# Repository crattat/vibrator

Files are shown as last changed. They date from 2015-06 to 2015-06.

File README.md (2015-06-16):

# vibrator
The vibrator is a device for vibration analysis for brushless motors and propellers. Currently it uses a MPU6050 chip for vibration analysis and an OPB732 photoelectric sensor to measure the revolution. All together is controlled with an Arduino Due and a touch display with a SD card interface. The results are evaluated with statistical analysis with R.

## Hardware
I'm using an Arduino Due together with an SD shield and 2.8" touch display. To wire the sensors and ESC a protoshield is put between SD shield and Arduino. In the cases folder you will find 3D designs and ready to print STL files for cases for the Arduino and also for the sensors to mount it properly. 

## Functions
Currently these functions are available:

* Measure and log revolution into a logfile to SD card
* Control a brushless motor via servo lib to run at predefined revolutions
* Automatically do a full vibration analysis at different revolutions
* Just watch all the sensor data graphically in a plot and as text
* Manage the files on SD card

## Restrictions
The MPU6050 is controlled through the I2C bus. This is quite limiting as it delivers not enough data per second. Just a few hundred samples is not enough to measure vibration frequency higher than a few hundred Hz. The results are good to compare motors or propellers reasonably anyway. For proper analysis of the concrete frequency with the strongest vibrations different sensors are required. I'm currently looking for better qualified or additional sensors.  

## Planned Enhancements
Extensions for the vibrator will be:

* A shunt to measure in addition the power consumption during the other tests
* A weighing cell to measure thrust during the tests. 

## Notes
To get the 2.8" SainSmart touch giving the correct coordinates the following defines have been adjusted in IDB02_touch.cpp:

```c++
#define PixSizeX	13.78

#define PixOffsX	411

#define PixSizeY	11.01

#define PixOffsY	378

```

The DueTimer lib conflicts with the Servo lib and the following define in the DueTimer.h file has been defined:

```c++
#define USING_SERVO_LIB	true
``` 
This makes several timers unavailabe.

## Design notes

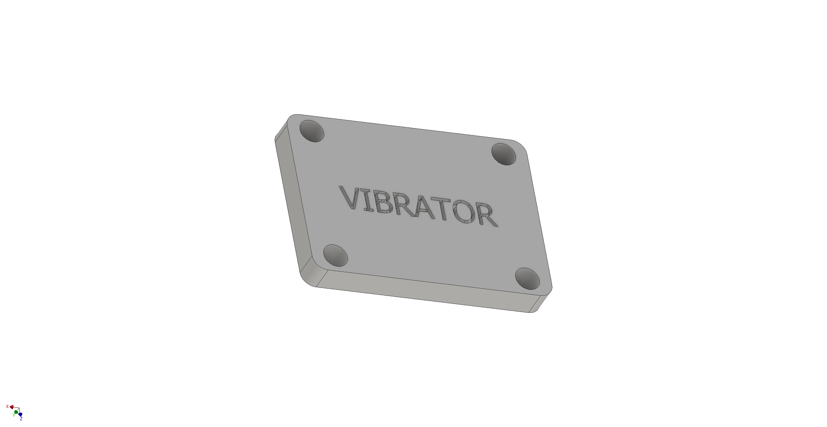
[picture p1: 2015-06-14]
Cases/MPU6050_CASE_TOP.jpg

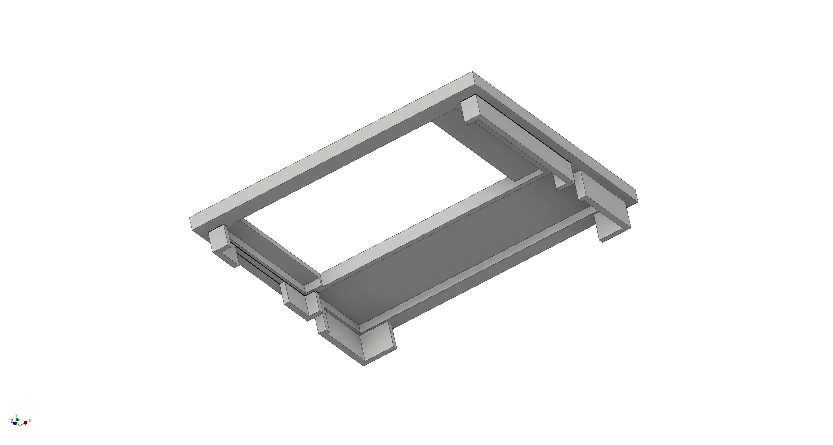
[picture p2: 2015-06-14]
Cases/ARDUINO_DUE_CASE_TOP.jpg

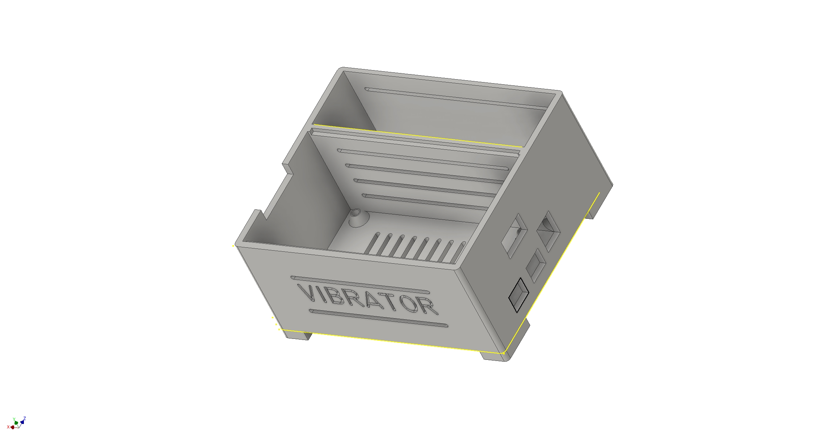
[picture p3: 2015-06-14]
Cases/ARDUINO_DUE_CASE_BOTTOM.jpg

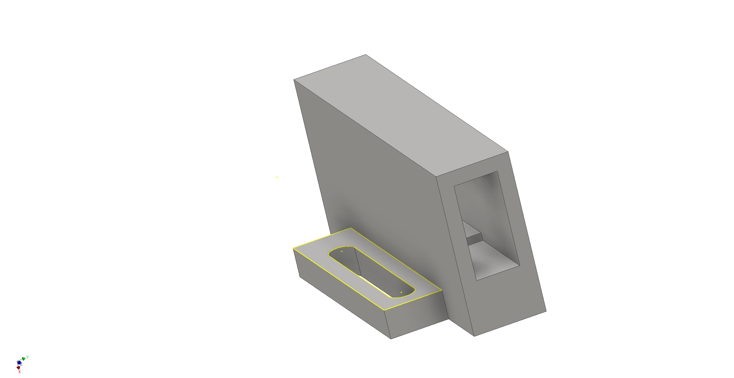
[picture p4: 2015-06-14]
Cases/OPB732_CASE_BOTTOM.jpg

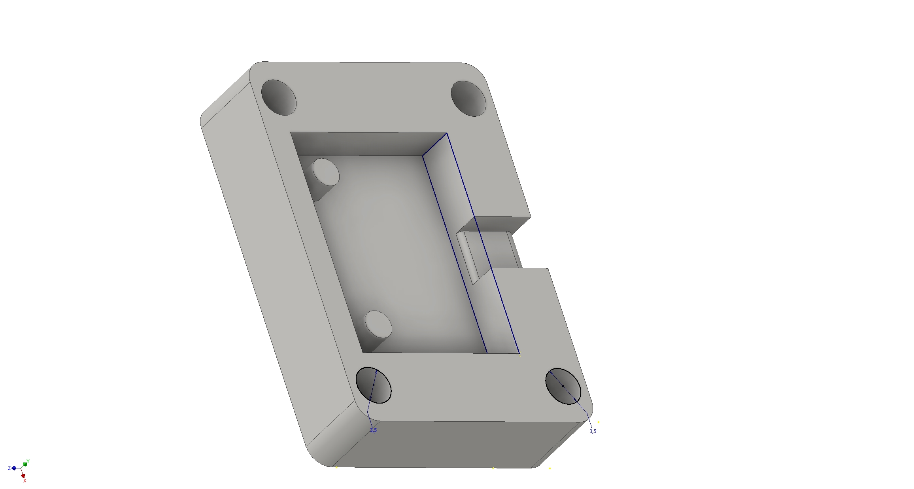
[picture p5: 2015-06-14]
Cases/MPU6050_CASE_BOTTOM.jpg

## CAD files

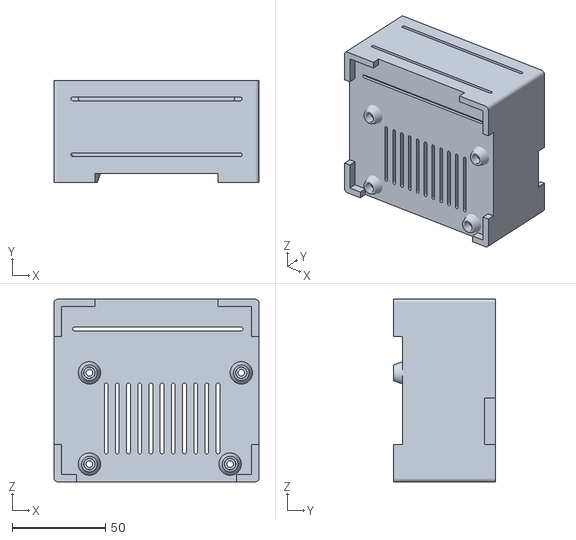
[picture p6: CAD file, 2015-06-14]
Cases/ARDUINO_DUE_CASE_BOTTOM.stl
110.0 x 55.0 x 98.0

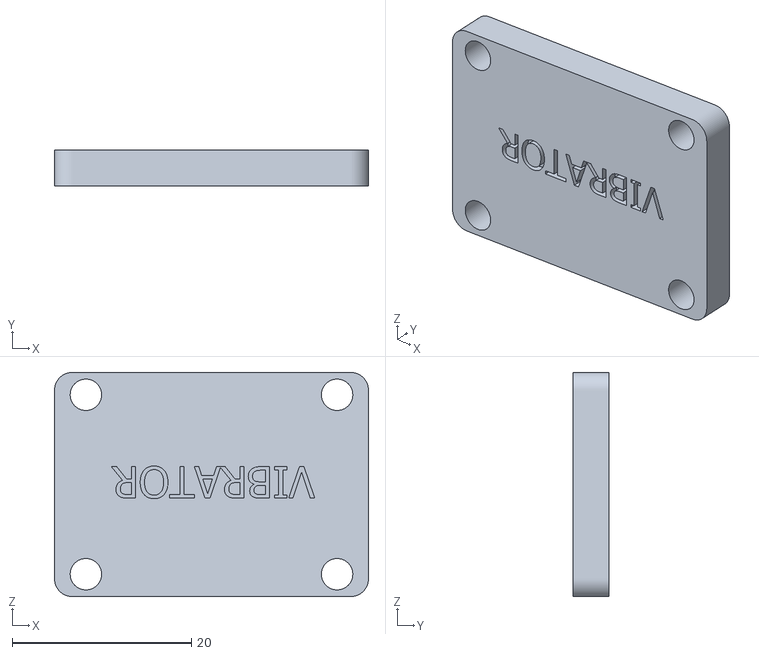
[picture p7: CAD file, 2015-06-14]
Cases/MPU6050_CASE_TOP.stl
35.0 x 4.00 x 25.0

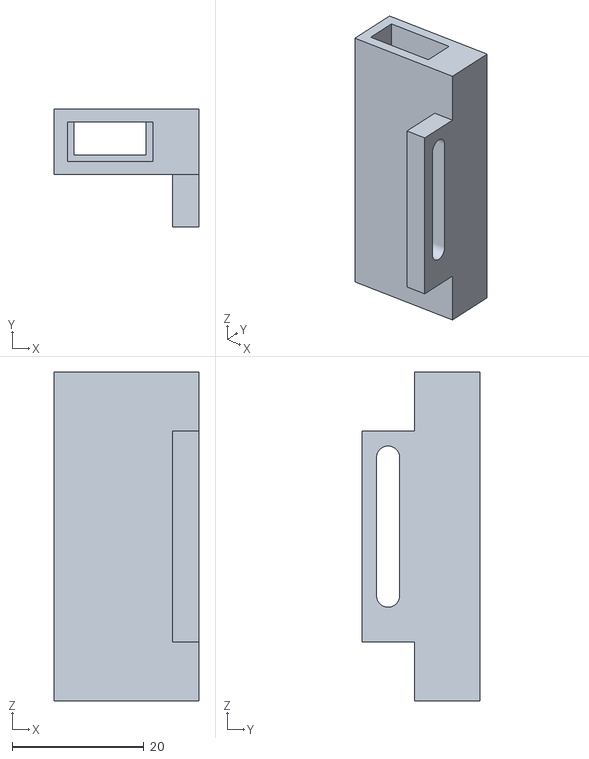
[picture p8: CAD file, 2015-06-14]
Cases/OPB732_CASE_BOTTOM.stl
22.0 x 18.0 x 50.0

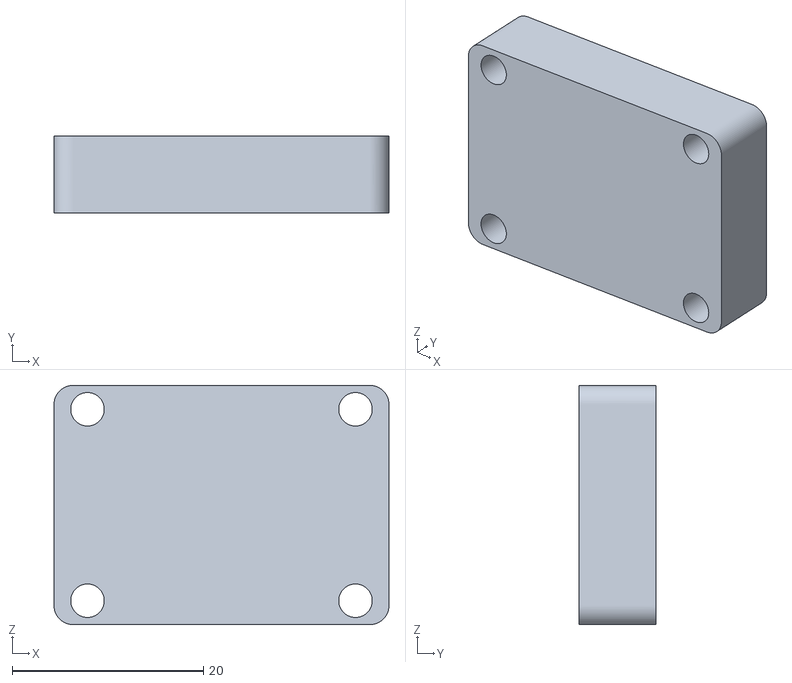
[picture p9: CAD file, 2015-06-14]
Cases/MPU6050_CASE_BOTTOM.stl
35.0 x 8.00 x 25.0

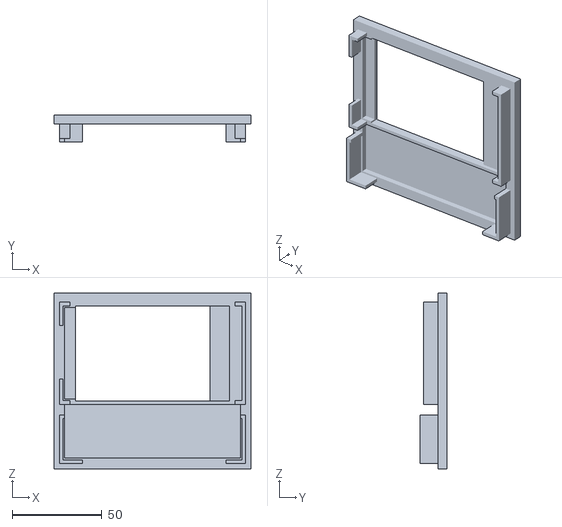
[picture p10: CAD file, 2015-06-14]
Cases/ARDUINO_DUE_CASE_TOP.stl
110.0 x 15.0 x 98.0

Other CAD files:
Cases/ARDUINO_DUE_CASE_BOTTOM.ipt
Cases/ARDUINO_DUE_CASE_TOP.ipt
Cases/MPU6050_CASE_BOTTOM.ipt
Cases/MPU6050_CASE_TOP.ipt
Cases/OPB732_CASE_BOTTOM.ipt

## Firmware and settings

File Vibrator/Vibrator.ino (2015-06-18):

// =========================================================================
// included libraries
// =========================================================================
#include "SPI.h"
#include <SdFat.h>
#include <UTFT.h>
#include <ITDB02_Touch.h>
#include <Servo.h>
#include <I2Cdev.h>
#include <MPU6050.h>

// =========================================================================
// Arduino Wire library is required if I2Cdev I2CDEV_ARDUINO_WIRE
// implementation is used in I2Cdev.h
// =========================================================================
#if I2CDEV_IMPLEMENTATION == I2CDEV_ARDUINO_WIRE
#include <Wire.h>
#endif

#include <DueTimer.h>

// =========================================================================
// includes from sketch
// =========================================================================
#include "Defines.h"
#include "IMUData.h"
#include "Logger.h"
#include "Menu.h"
#include "Screen.h"
#include "Views.h"

// =========================================================================
// devices
// =========================================================================
Logger            _logger;
Screen            _screen;
MPU6050           _mpu6050;

// =========================================================================
// navigation and display stuff
// =========================================================================
bool              _navigationNeedsUpdate = false;
Menu*             _activeMenu = 0;
int16_t           _activeAction = 0;
uint32_t          _last100msUpdate = 0;
uint32_t          _last25msUpdate = 0;
uint32_t          _last10msUpdate = 0;

Menu              _mainMenu(&_screen, "Vibrator V1");
Menu              _sensorCheckMenu(&_screen, "Sensor Check");
Menu              _revMeterMenu(&_screen, "Rev Meter");
Menu              _revControlMenu(&_screen, "Rev Control");
Menu              _vibMeterMenu(&_screen, "Vibration Meter");
Menu              _settingsMenu(&_screen, "Settings");

Views             _views(&_screen);

// =========================================================================
// revolution measuring
// =========================================================================
volatile bool     _revlow = false;
volatile int32_t  _revpeaks = 0;
volatile int32_t  _revcount = 0;
volatile int32_t  _currentRevolution = 0;
volatile int32_t  _revolution = 0;

// =========================================================================
// IMU measure data
// =========================================================================
IMUData           _imuData;

// =========================================================================
// control motor
// =========================================================================
Servo  _esc;
volatile int      _escTargetRev = 0;
volatile int      _escCurrentLevel = 0;
volatile int      _escLastLevel = 0;

// =========================================================================
// states for automatic measuring
// =========================================================================
uint32_t         _testStart;
uint8_t          _step;

volatile  int32_t _revvalue = 0;

// =========================================================================
// 60 kHz timer to measure the revolution. To be accurate enough it is
// required to get updates every 60deg of rotation, i.e. the measuring
// unit that is used must indicate 6 times per rotation a change. In
// the original project this is done by glueing 6 markes of 3deg width
// on the engine cone.
// =========================================================================
void measureRevolutionTimer()
{
  // measure revolution
  // wait until channel 0 completed conversion
  while ((ADC->ADC_ISR & 0x80) == 0);
  // read channel 0
  _revvalue = ADC->ADC_CDR[7];
  // this is the normal analogRead which takes 40us by default, which is too slow for 60 kHz
  // int32_t _revvalue = analogRead(REV_METER_PIN);
  _revcount++;

  // here we measure low-high slopes
  if (_revvalue < 1000)
  {
    // if already low don't measure
    if (!_revlow)
    {
      _revpeaks++;
    }
    _revlow = true;
  }
  else
  {
    _revlow = false;
  }

  _currentRevolution = TIMER_REVOLUTION_FREQUENCY * _revpeaks / _revcount;

  if (_revcount > TIMER_REVOLUTION_FREQUENCY / 6)
  {
    _revolution = _currentRevolution;
    _revcount = 0;
    _revpeaks = 0;
  }
}


// =========================================================================
// 50 Hz timer to update the servo when any related mode is active.
// The current revolution is compared to the wanted target revolution.
// If current revolution is lower or higher the output PWM is increased
// or decreased correspondingly.
// =========================================================================
void controlServoTimer()
{
  switch (_activeAction)
  {
    case ACTION_ESC_CONTROL_1000U:
    case ACTION_ESC_CONTROL_2000U:
    case ACTION_ESC_CONTROL_3000U:
    case ACTION_ESC_CONTROL_4000U:
    case ACTION_ESC_CONTROL_5000U:
    case ACTION_VIB_METER_RECORD:

      uint16_t revMin = _revolution * 10;

      if (abs(revMin - _escTargetRev) < 100)
      {
        return;
      }

      if (revMin < _escTargetRev)
      {
        _escCurrentLevel++;
      }
      if (revMin > _escTargetRev)
      {
        _escCurrentLevel--;
      }

      if (_escCurrentLevel > REV_ESC_RANGE)
      {
        _escCurrentLevel = REV_ESC_RANGE;
      }
      else if (_escCurrentLevel < 0)
      {
        _escCurrentLevel = 0;
      }

      // don't set the same timing again
      if (_escLastLevel != _escCurrentLevel)
      {
        _escLastLevel = _escCurrentLevel;
        _esc.writeMicroseconds(map(_escCurrentLevel, 0, REV_ESC_RANGE, 800, 2000));
      }
      break;
  }
}

// =========================================================================
// Collect all sensor data in the imu data.
// =========================================================================
void updateSensorSamples()
{
  // collect from MPU6050 and revolution counter
  _mpu6050.getMotion6(&_imuData.ax, &_imuData.ay, &_imuData.az, &_imuData.gx, &_imuData.gy, &_imuData.gz);
  _imuData.t = _mpu6050.getTemperature();
  _imuData.r = _revolution;

  // just call logger which will log if recording is active
  _logger.writeAll(_revolution, _imuData);
}

// =========================================================================
// Initializes the servo.
// =========================================================================
void initializeServo()
{
  _esc.attach(SERVO_OUT);
  stopServo();
  Serial.println("Servo Initialized");
}

// =========================================================================
// Stops the servo.
// =========================================================================
void stopServo()
{
  _escTargetRev = 0;
  _escCurrentLevel = 0;
  _escLastLevel = 0;
  _esc.writeMicroseconds(map(0, 0, REV_ESC_RANGE, 800, 2000));
  Serial.println("Servo stopped");
}

// =========================================================================
// Initializes the MPU6050 and I2C bus.
// =========================================================================
void initializeIMU()
{
  // start I2C
#if I2CDEV_IMPLEMENTATION == I2CDEV_ARDUINO_WIRE
  Wire.begin();
  // set I2C speed to 400khz, this might not work for all Arduino versions
  Wire.setClock(400000l);
  Serial.println("Using wire");
#elif I2CDEV_IMPLEMENTATION == I2CDEV_BUILTIN_FASTWIRE
  Fastwire::setup(400, true);
  Serial.println("Using fastwire");
#endif

  _mpu6050.initialize();

  Serial.println(_mpu6050.testConnection() ? "MPU6050 connected" : "MPU6050 failed");

  // todo calibrate IMU
}

// =========================================================================
// Resets the screen to be redrawn and changes to another action, if action
// is defined (> -1).
// =========================================================================
bool updateScreenSettings(int16_t activeAction, Menu* activeMenu, bool resetView)
{
  if (resetView)
  {
    _views.reset();
  }

  if (activeMenu)
  {
    _activeMenu = activeMenu;
  }

  if (activeAction >= 0)
  {
    _activeAction = activeAction;
  }
  _navigationNeedsUpdate = true;
}

// =========================================================================
// This function starts a specified action.
// =========================================================================
void runAction(int16_t action)
{
  Serial.println(action);

  switch (action)
  {
    // ==========================================
    // Vibration measuring
    // ==========================================
    case ACTION_VIB_METER:
      updateScreenSettings(action, &_vibMeterMenu, true);
      break;
    case ACTION_VIB_METER_CLOSE:
      _vibMeterMenu.reset();
      updateScreenSettings(0, &_mainMenu, true);
      break;
    case ACTION_VIB_METER_RECORD:
      _activeAction = action;
      stopServo();
      if (!_logger.recording())
      {
        delay(10);
        _escTargetRev = 1000;
        _testStart = millis();
        _step = 1;
        _logger.startRecording("vib_");
      }
      else
      {
        _testStart = 0;
        _step = 0;
        _logger.stopRecording();
      }
      break;
    // ==========================================
    // Sensor checks
    // ==========================================
    case ACTION_SENSOR_CHECK:
      updateScreenSettings(action, &_sensorCheckMenu, true);
      break;
    case ACTION_CLOSE_SENSOR_CHECK:
      _sensorCheckMenu.reset();
      updateScreenSettings(0, &_mainMenu, true);
      break;
    case ACTION_TOGGLE_SENSOR_CHECK:
      _views.toggleGraphFullScreen();
      updateScreenSettings(-1, 0, false);
      break;
    // ==========================================
    // Revolution measuring
    // ==========================================
    case ACTION_REV_METER:
      updateScreenSettings(action, &_revMeterMenu, true);
      break;
    case ACTION_REV_METER_RECORD:
      _logger.toggleRecording("rev_");
      break;
    case ACTION_REV_METER_CLOSE:
      _logger.stopRecording();
      _sensorCheckMenu.reset();
      updateScreenSettings(0, &_mainMenu, true);
      break;
    // ==========================================
    // ESC control
    // ==========================================
    case ACTION_ESC_CONTROL:
      updateScreenSettings(action, &_revControlMenu, true);
      break;
    case ACTION_ESC_CONTROL_STOP:
      _activeAction = ACTION_ESC_CONTROL;
      stopServo();
      break;
    case ACTION_ESC_CONTROL_CLOSE:
      stopServo();
      _sensorCheckMenu.reset();
      updateScreenSettings(0, &_mainMenu, true);
      break;
    case ACTION_ESC_CONTROL_1000U:
    case ACTION_ESC_CONTROL_2000U:
    case ACTION_ESC_CONTROL_3000U:
    case ACTION_ESC_CONTROL_4000U:
    case ACTION_ESC_CONTROL_5000U:
      _activeAction = action;
      stopServo();
      delay(100);
      switch (action)
      {
        case ACTION_ESC_CONTROL_1000U:
          _escTargetRev = 1000;
          break;
        case ACTION_ESC_CONTROL_2000U:
          _escTargetRev = 2000;
          break;
        case ACTION_ESC_CONTROL_3000U:
          _escTargetRev = 3000;
          break;
        case ACTION_ESC_CONTROL_4000U:
          _escTargetRev = 4000;
          break;
        case ACTION_ESC_CONTROL_5000U:
          _escTargetRev = 5000;
          break;
      }
      break;
    // ==========================================
    // Settings
    // ==========================================
    case ACTION_SETTINGS:
      updateScreenSettings(ACTION_SETTINGS, &_settingsMenu, true);
      break;
    case ACTION_SETTINGS_CLOSE:
      updateScreenSettings(0, &_mainMenu, true);
      break;
  }
}

// =========================================================================
// This update function is called every 25 milliseconds.
// =========================================================================
void update25()
{
  if (_navigationNeedsUpdate)
  {
    if (_activeMenu)
    {
      _activeMenu->draw();
    }
    _navigationNeedsUpdate = false;
  }

  switch (_activeAction)
  {
    case ACTION_SENSOR_CHECK:
      _views.updateSensorCheck(_imuData);
      break;
    case ACTION_VIB_METER:
      _views.updateSensorCheck(_imuData);
      break;
    case ACTION_REV_METER:
      _views.updateRevMeter(_imuData);
      break;
    case ACTION_ESC_CONTROL:
      _views.updateRevMeter(_imuData);
      break;
    case ACTION_ESC_CONTROL_1000U:
    case ACTION_ESC_CONTROL_2000U:
    case ACTION_ESC_CONTROL_3000U:
    case ACTION_ESC_CONTROL_4000U:
    case ACTION_ESC_CONTROL_5000U:
      _views.updateRevMeter(_imuData);
      break;
    case ACTION_VIB_METER_RECORD:
      _views.updateSensorCheck(_imuData);
      if (millis() - _testStart > 10000)
      {
        switch (_step)
        {
          case 1:
            _step++;
            _testStart = millis();
            _escTargetRev = 2000;
            break;
          case 2:
            _step++;
            _testStart = millis();
            _escTargetRev = 3000;
            break;
          default:
            _logger.stopRecording();
            _testStart = 0;
            _step = 0;
            _escTargetRev = 0;
            delay(100);
            _vibMeterMenu.reset();
            _vibMeterMenu.draw();
            updateScreenSettings(ACTION_VIB_METER, &_vibMeterMenu, true);
            stopServo();
            break;
        }
      }
      break;
    case ACTION_SETTINGS:
      _views.updateSettings(_logger.GetSdFat());
      break;
  }
}

// =========================================================================
// Initialization
// =========================================================================
void setup()
{
  Serial.begin(38400);
  Serial.println("Initializing");

  _screen.initialize();

  Serial.println("Display and touch initialized");

  if (!_logger.initialize(53, 10))
  {
    Serial.println("Logger failed");
  }
  else
  {
    Serial.println("Logger initialized");
  }

  _mainMenu.add(10,  38, 300,  30, ACTION_REV_METER, "Rev Meter");
  _mainMenu.add(10,  38 + 1 * 39, 300,  30, ACTION_ESC_CONTROL, "Rev Control");
  _mainMenu.add(10,  38 + 2 * 39, 300,  30, ACTION_VIB_METER, "Vibration Meter");
  _mainMenu.add(10,  38 + 3 * 39, 300,  30, ACTION_SENSOR_CHECK, "Sensor Check");
  _mainMenu.add(10,  38 + 4 * 39, 300,  30, ACTION_SETTINGS, "Settings");

  _sensorCheckMenu.add(272, 5, 20, 20, ACTION_TOGGLE_SENSOR_CHECK, BUTTON_TOGGLE);
  _sensorCheckMenu.add(296, 5, 20, 20, ACTION_CLOSE_SENSOR_CHECK, BUTTON_CLOSE);

  _revMeterMenu.add(272, 5, 20, 20, ACTION_REV_METER_RECORD, BUTTON_RECORD);
  _revMeterMenu.add(296, 5, 20, 20, ACTION_REV_METER_CLOSE, BUTTON_CLOSE);

  _revControlMenu.add(296,  5, 19, 19, ACTION_ESC_CONTROL_CLOSE, BUTTON_CLOSE);
  _revControlMenu.add(5,   40, 80, 25, ACTION_ESC_CONTROL_STOP, "STOP");
  _revControlMenu.add(95,  40, 35, 25, ACTION_ESC_CONTROL_1000U, "1k");
  _revControlMenu.add(140, 40, 35, 25, ACTION_ESC_CONTROL_2000U, "2k");
  _revControlMenu.add(185, 40, 35, 25, ACTION_ESC_CONTROL_3000U, "3k");
  _revControlMenu.add(230, 40, 35, 25, ACTION_ESC_CONTROL_4000U, "4k");
  _revControlMenu.add(275, 40, 35, 25, ACTION_ESC_CONTROL_5000U, "5k");

  _vibMeterMenu.add(272, 5, 19, 19, ACTION_VIB_METER_RECORD, BUTTON_RECORD);
  _vibMeterMenu.add(296, 5, 19, 19, ACTION_VIB_METER_CLOSE, BUTTON_CLOSE);

  _settingsMenu.add(296, 5, 19, 19, ACTION_SETTINGS_CLOSE, BUTTON_CLOSE);

  _activeMenu = &_mainMenu;
  _navigationNeedsUpdate = true;

  Serial.println("Navigation initialized");

  initializeServo();

  initializeIMU();

  // initialize the ADC to run in free running mode. This allows conversion in 1 us.
  ADC->ADC_MR |= 0x80;
  // start conversion
  ADC->ADC_CR = 2;
  // enable ADC channel 0
  ADC->ADC_CHER = 0x80;

  delay(500);

  Timer1.attachInterrupt(measureRevolutionTimer).setFrequency(TIMER_REVOLUTION_FREQUENCY).start();
  Timer6.attachInterrupt(controlServoTimer).setFrequency(TIMER_SERVO_FREQUENCY).start();
  Serial.println("Timers started");

  delay(500);

  Serial.println("Initialization done");
}

// =========================================================================
// Loop
// =========================================================================
void loop()
{
  // run updates every 100ms
  uint32_t t = millis();
  if (t - _last100msUpdate > 100)
  {
    _last100msUpdate = t;
    if (_screen.touched())
    {
      Serial.println(_screen.touchCoordinatesString());
      if (_activeMenu)
      {
        int16_t action = _activeMenu->check();
        if (action > 0)
        {
          runAction(action);
          action = 0;
        }
      }
    }
  }

  // run updates every 25ms
  t = millis();
  if (t - _last25msUpdate > 25)
  {
    _last25msUpdate = t;
    update25();
    Serial.println(_revvalue);
  }

  // run updates every 10ms
  t = millis();
  if (t - _last10msUpdate > 10)
  {
    _last10msUpdate = t;
    updateSensorSamples();
  }
}

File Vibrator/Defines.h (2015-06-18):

#ifndef Defines_h
#define Defines_h

// =========================================================================
// Hardware specific settings
// =========================================================================

// The photo sensor is connected to this pin
#define REV_METER_PIN A0

// The range of ESC in microseconds is 1200, 0 means off, 1200 means 100%
#define REV_ESC_RANGE 1200

// We are using PWM 9 port
#define SERVO_OUT 9

// Timer frequency for revolution measuring
#define TIMER_REVOLUTION_FREQUENCY 60000

// Timer frequency for updating the servo
#define TIMER_SERVO_FREQUENCY 50

#endif

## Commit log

2015-06-14 Initial add of CAD files.
    [ARDUINO_DUE_CASE_BOTTOM.ipt, ARDUINO_DUE_CASE_BOTTOM.stl, ARDUINO_DUE_CASE_TOP.ipt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]
2015-06-14 Renamed folder with sketch due to Arduino ide restrictions.
2015-06-18 Enabled ADC free running mode.
